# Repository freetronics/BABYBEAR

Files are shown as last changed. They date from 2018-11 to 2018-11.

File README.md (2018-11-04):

Freetronics Baby Bear
=====================
Copyright 2013-2018 Freetronics Pty Ltd  <www.freetronics.com>  

The Baby Bear is an Arduino Compatible Board based on the ATmega1284P
MCU, which means it's compatible with projects designed for the Arduino
Uno but has more memory and I/O capabilities.

Features:

 * USB-C connector
 * Prototyping area
 * LEDs visible on the edge when a shield is fitted
 * Overlay guide where you need it (both top and bottom)
 * D13 pin works for everything
 * Mounting holes and power pads
 * All connections in the same place

You can find more information at:

  http://www.freetronics.com.au/babybear

INSTALLATION
------------
The design is saved as an EAGLE project. EAGLE PCB design software is
available from www.cadsoftusa.com free for non-commercial use. To use
this project download it and place the directory containing these files
into the "eagle" directory on your computer. Then open EAGLE and
navigate to the project.

INSTALLATION
------------
The design is saved as an EAGLE project. EAGLE PCB design software is
available from www.cadsoftusa.com free for non-commercial use. To use
this project download it and place the directory containing these files
into the "eagle" directory on your computer.

DISTRIBUTION
------------
The specific terms of distribution of this project are governed by the
license referenced below.

LICENSE
-------
Licensed under the TAPR Open Hardware License (www.tapr.org/OHL).
The "license" folder within this repository also contains a copy of
this license in plain text format.

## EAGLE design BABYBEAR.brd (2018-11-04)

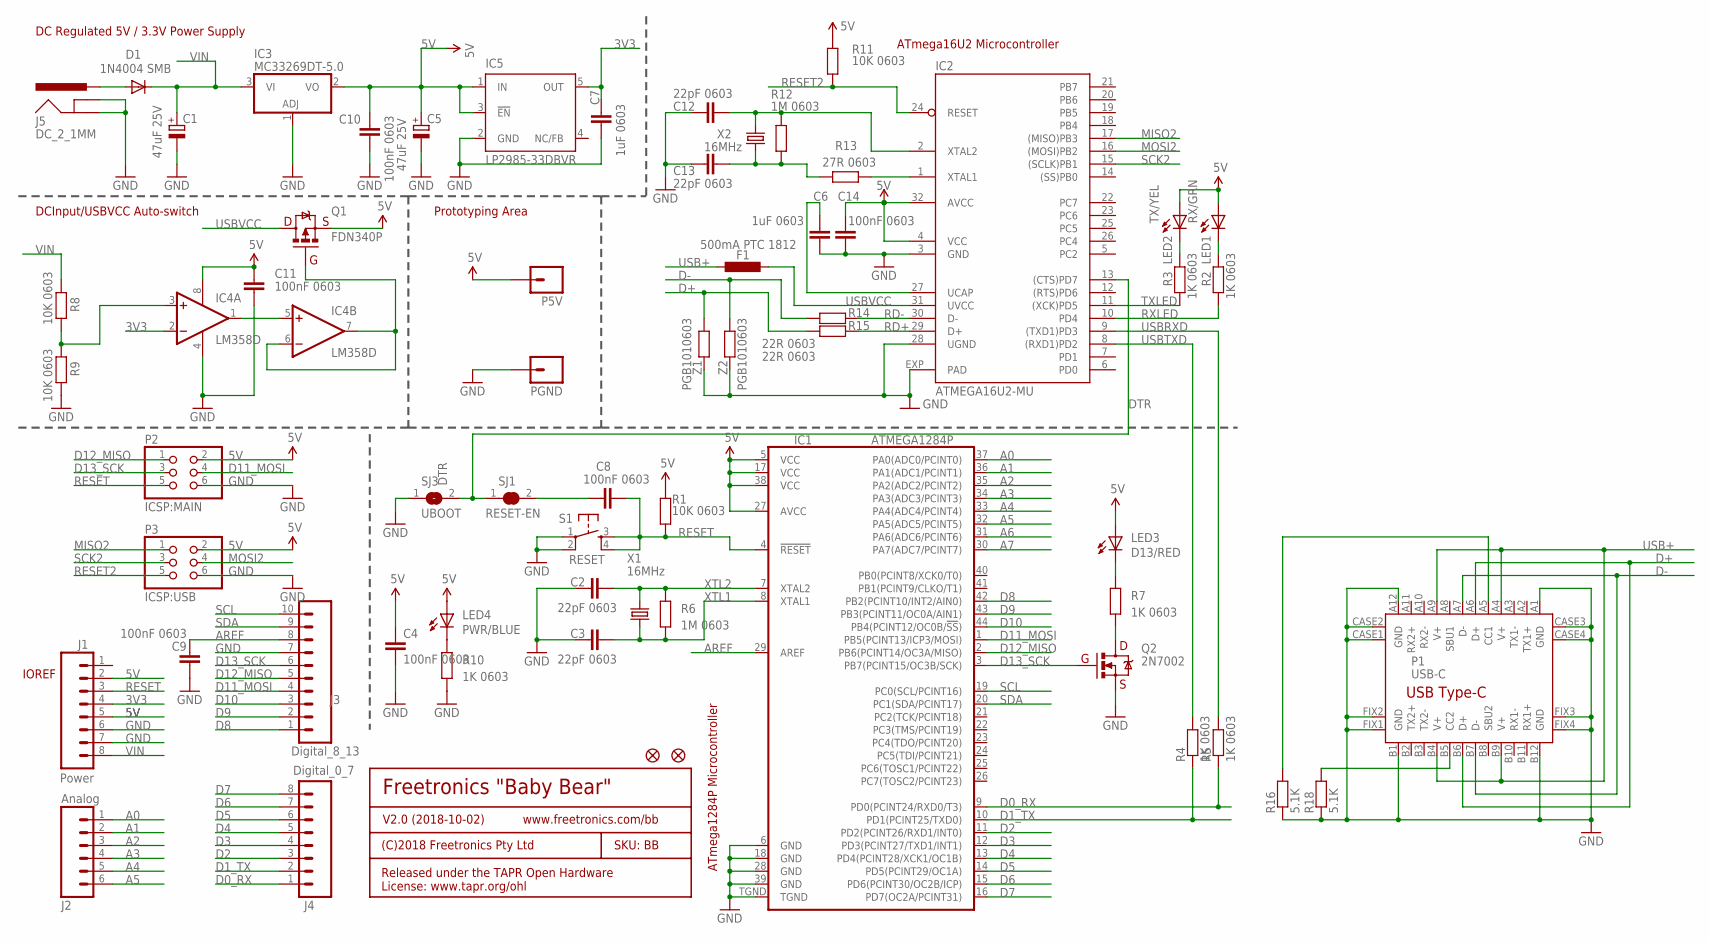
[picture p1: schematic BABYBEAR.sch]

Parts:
C1, C5: 47uF 25V; PANASONIC_D
C2, C3, C12, C13: 22pF 0603; 0603
C4, C8, C9, C10, C11, C14: 100nF 0603; 0603
C6, C7: 1uF 0603; 0603
D1: 1N4004 SMB; SMB-DIODE
F1: 500mA PTC 1812; L1812
IC1: ATMEGA1284P; QFN-44M1
IC2: ATMEGA16U2-MU; ATMEL_QFN32
IC3: MC33269DT-5.0; DPACK
IC4: LM358D; SO08
IC5: LP2985-33DBVR; TEXAS_SOT23-DBV
J1: Power; 1X08
J2: Analog; 1X06
J3: Digital_8_13; 1X10
J4: Digital_0_7; 1X08
J5: DC_2_1MM; POWER_JACK_PTH_SLOTS
LED1: RX/GRN; LED-0603
LED2: TX/YEL; LED-0603
LED3: D13/RED; LED-0603
LED4: PWR/BLUE; LED-0603
P1: USB-C; USB-C-U52A
P2: ICSP:MAIN; 2X03
P3: ICSP:USB; 2X03
P5V: M01SMD; LUXEON-PAD
PGND: M01SMD; LUXEON-PAD
Q1: FDN340P; SOT23
Q2: 2N7002; SOT23-3
R1, R8, R9, R11: 10K 0603; 0603
R2, R3, R4, R5, R7, R10: 1K 0603; 0603
R6, R12: 1M 0603; 0603
R13: 27R 0603; 0603
R14, R15: 22R 0603; 0603
R16, R18: 5.1K; 0603
S1: RESET; TACTILE_SWITCH_SMD
SJ1: RESET-EN; SJC
SJ3: UBOOT; SJ
U$5, U$14: FIDUCIAL1X2.5; FIDUCIAL-1X2.5
X1, X2: 16MHz; HC49U-V
Z1, Z2: PGB1010603; 0603

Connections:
3V3: C7.2, IC4.2 (-IN), IC5.5 (OUT), J1.4
5V: C4.1, C5.+, C10.1, C11.1, C14.1, IC1.5 (VCC), IC1.17 (VCC), IC1.27 (AVCC), IC1.38 (VCC), IC2.4 (VCC), IC2.32 (AVCC), IC3.2 (VO), IC4.8 (V+), IC5.1 (IN), IC5.3 (!EN), J1.2, J1.5, LED1.A, LED2.A, LED3.A, LED4.A, P2.2, P3.2, P5V.P$1, Q1.2 (S), R1.2, R11.2
A0: IC1.37 (PA0(ADC0/PCINT0)), J2.1
A1: IC1.36 (PA1(ADC1/PCINT1)), J2.2
A2: IC1.35 (PA2(ADC2/PCINT2)), J2.3
A3: IC1.34 (PA3(ADC3/PCINT3)), J2.4
A4: IC1.33 (PA4(ADC4/PCINT4)), J2.5
A5: IC1.32 (PA5(ADC5/PCINT5)), J2.6
A6: IC1.31 (PA6(ADC6/PCINT6))
A7: IC1.30 (PA7(ADC7/PCINT7))
AREF: C9.1, IC1.29 (AREF), J3.8
D0_RX: IC1.9 (PD0(PCINT24/RXD0/T3)), J4.1, R5.1
D1_TX: IC1.10 (PD1(PCINT25/TXD0)), J4.2, R4.1
D2: IC1.11 (PD2(PCINT26/RXD1/INT0)), J4.3
D3: IC1.12 (PD3(PCINT27/TXD1/INT1)), J4.4
D4: IC1.13 (PD4(PCINT28/XCK1/OC1B)), J4.5
D5: IC1.14 (PD5(PCINT29/OC1A)), J4.6
D6: IC1.15 (PD6(PCINT30/OC2B/ICP)), J4.7
D7: IC1.16 (PD7(OC2A/PCINT31)), J4.8
D8: IC1.42 (PB2(PCINT10/INT2/AIN0)), J3.1
D9: IC1.43 (PB3(PCINT11/OC0A/AIN1)), J3.2
D10: IC1.44 (PB4(PCINT12/OC0B/!SS!)), J3.3
D11_MOSI: IC1.1 (PB5(PCINT13/ICP3/MOSI)), J3.4, P2.4
D12_MISO: IC1.2 (PB6(PCINT14/OC3A/MISO)), J3.5, P2.1
D13_SCK: IC1.3 (PB7(PCINT15/OC3B/SCK)), J3.6, P2.3, Q2.1 (G)
D+: P1.A6 (D+), P1.B6 (D+), R15.2, Z1.1
D-: P1.A7 (D-), P1.B7 (D-), R14.2, Z2.1
DTR: IC2.13 ((CTS)PD7), SJ1.1, SJ3.2
GND: C1.-, C2.1, C3.1, C4.2, C5.-, C6.2, C7.1, C9.2, C10.2, C11.2, C12.1, C13.1, C14.2, IC1.6 (GND), IC1.18 (GND), IC1.28 (GND), IC1.39 (GND), IC1.TGND, IC2.3 (GND), IC2.28 (UGND), IC2.EXP (PAD), IC3.1 (ADJ), IC4.4 (V-), IC5.2 (GND), J1.6, J1.7, J3.7, J5.GND, J5.GNDBREAK, P1.A1 (GND), P1.A12 (GND), P1.B1 (GND), P1.B12 (GND), P1.CASE1 (GND), P1.CASE2 (GND), P1.CASE3 (GND), P1.CASE4 (GND), P1.FIX1 (GND), P1.FIX2 (GND), P1.FIX3 (GND), P1.FIX4 (GND), P2.6, P3.6, PGND.P$1, Q2.2 (S), R9.1, R10.1, R16.1, R18.1, S1.1, S1.2, SJ3.1, Z1.2, Z2.2
MISO2: IC2.17 ((MISO)PB3), P3.1
MOSI2: IC2.16 ((MOSI)PB2), P3.4
unnamed: C8.1, SJ1.2
unnamed: IC2.1 (XTAL1), R13.1
unnamed: P1.B5 (CC2), R18.2
unnamed: LED3.C, R7.2
unnamed: Q2.3 (D), R7.1
unnamed: P1.A5 (CC1), R16.2
unnamed: D1.A, J5.PWR
unnamed: IC4.3 (+IN), R8.1, R9.2
unnamed: IC4.1 (OUT), IC4.5 (+IN)
unnamed: LED1.C, R2.2
unnamed: IC4.6 (-IN), IC4.7 (OUT), Q1.1 (G)
unnamed: LED2.C, R3.2
unnamed: LED4.C, R10.2
unnamed: C12.2, IC2.2 (XTAL2), R12.2, X2.2
unnamed: C13.2, R12.1, R13.2, X2.1
unnamed: C6.1, IC2.27 (UCAP)
RD+: IC2.29 (D+), R15.1
RD-: IC2.30 (D-), R14.1
RESET: C8.2, IC1.4 (!RESET), J1.3, P2.5, R1.1, S1.3, S1.4
RESET2: IC2.24 (RESET), P3.5, R11.1
RXLED: IC2.10 (PD4), R2.1
SCK2: IC2.15 ((SCLK)PB1), P3.3
SCL: IC1.19 (PC0(SCL/PCINT16)), J3.10
SDA: IC1.20 (PC1(SDA/PCINT17)), J3.9
TXLED: IC2.11 ((XCK)PD5), R3.1
USB+: F1.1, P1.A4 (V+), P1.A9 (V+), P1.B4 (V+), P1.B9 (V+)
USBRXD: IC2.9 ((TXD1)PD3), R5.2
USBTXD: IC2.8 ((RXD1)PD2), R4.2
USBVCC: F1.2, IC2.31 (UVCC), Q1.3 (D)
VIN: C1.+, D1.C, IC3.3 (VI), J1.8, R8.2
XTL1: C3.2, IC1.8 (XTAL1), R6.1, X1.1
XTL2: C2.2, IC1.7 (XTAL2), R6.2, X1.2

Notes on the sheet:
Prototyping Area
DCInput/USBVCC Auto-switch
DC Regulated 5V / 3.3V Power Supply
ATmega16U2 Microcontroller
Freetronics "Baby Bear"
V2.0 (2018-10-02)
SKU: BB
(C)2018 Freetronics Pty Ltd
Released under the TAPR Open Hardware License: www.tapr.org/ohl
www.freetronics.com/bb
IOREF
ATmega1284P Microcontroller

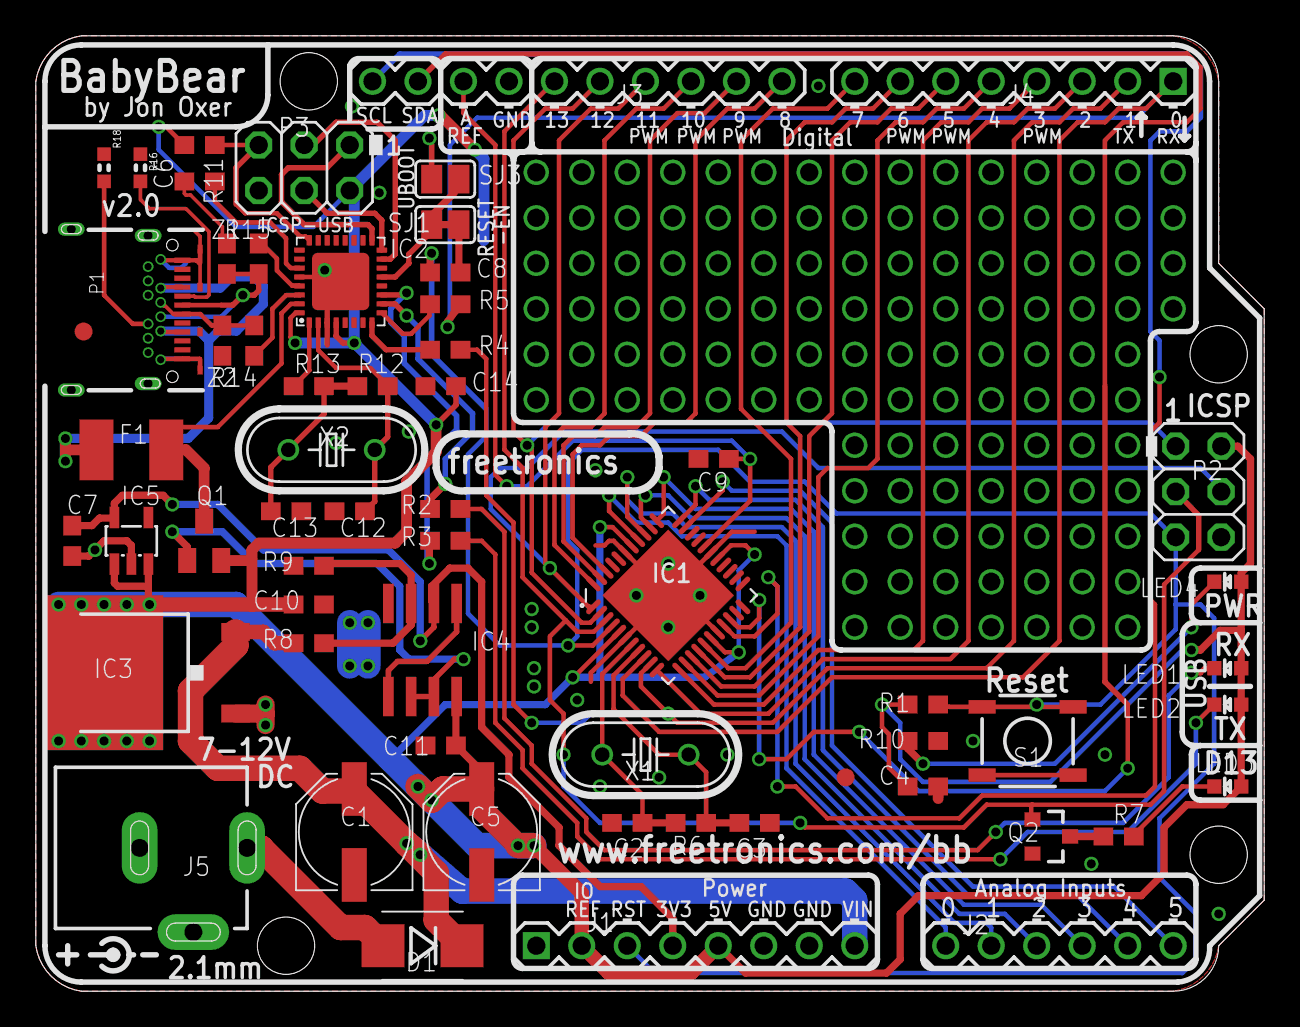
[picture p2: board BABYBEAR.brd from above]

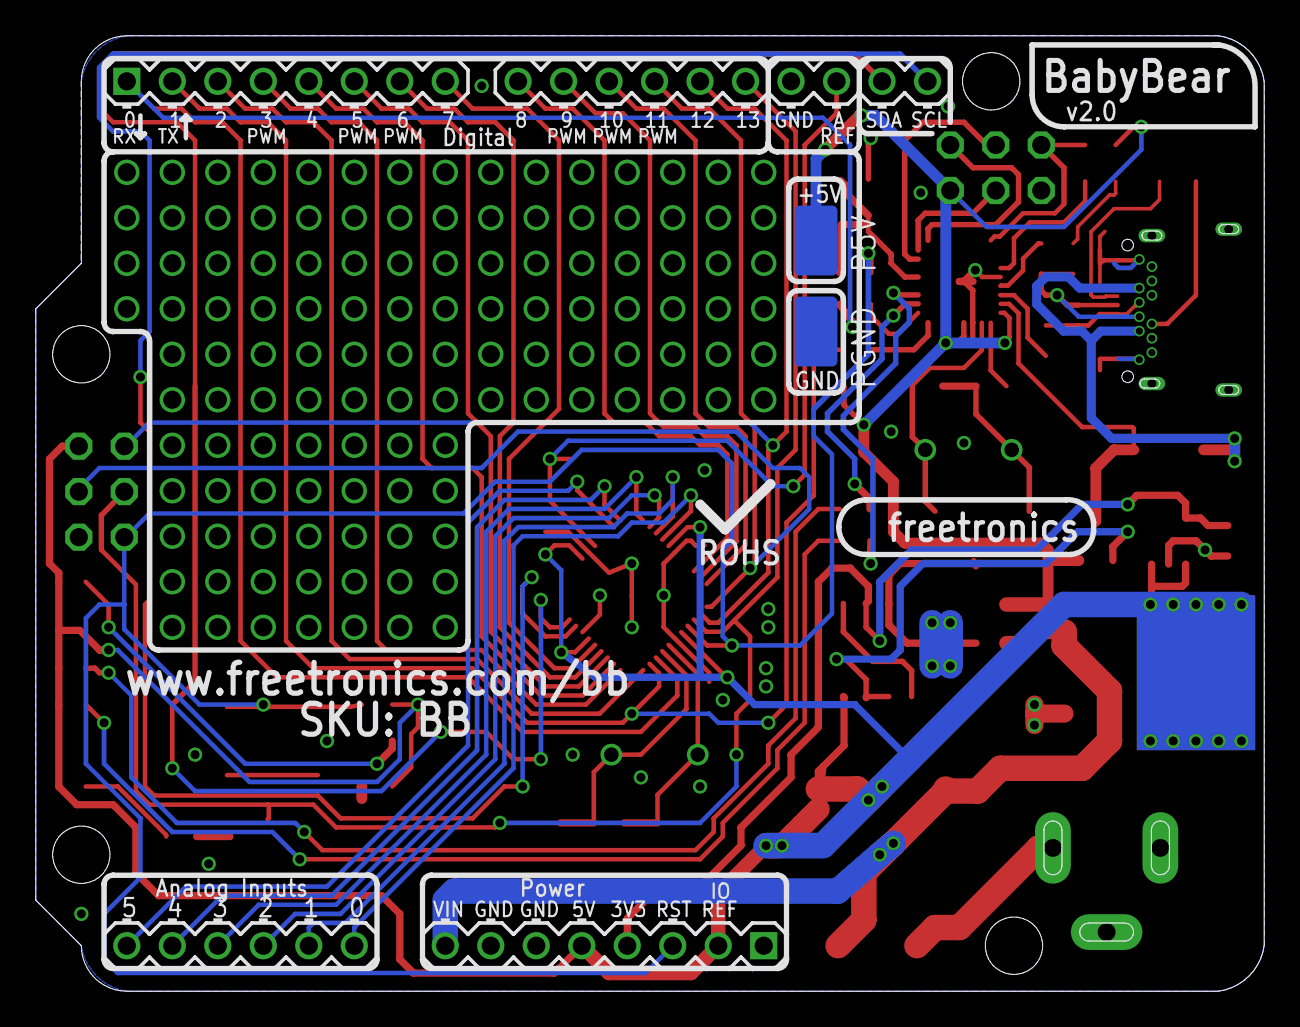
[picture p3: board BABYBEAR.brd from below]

Board: 2 copper layers, 68.6 x 53.3 mm, 63 parts (2 on the bottom side), 61 nets.

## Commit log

2018-03-27 Import of old project
    [BABYBEAR.brd, BABYBEAR.sch]
2018-11-04 Changed USB connector to USB-C for v2.0 release
    [BABYBEAR.brd, BABYBEAR.sch]

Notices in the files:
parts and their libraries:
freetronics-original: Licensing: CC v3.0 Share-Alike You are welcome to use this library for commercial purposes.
